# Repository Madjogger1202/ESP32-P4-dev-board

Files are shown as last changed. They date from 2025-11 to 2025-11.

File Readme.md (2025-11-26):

# ESP32-P4-dev-board

> High-performance vision and control board based on **ESP32-P4 (32 MB internal RAM)**.  
> Designed as a modern replacement for **OpenMV-style boards** built on STM32H7,  
> with integrated USB interfaces, Wi-Fi, camera connector, and expansion ports.

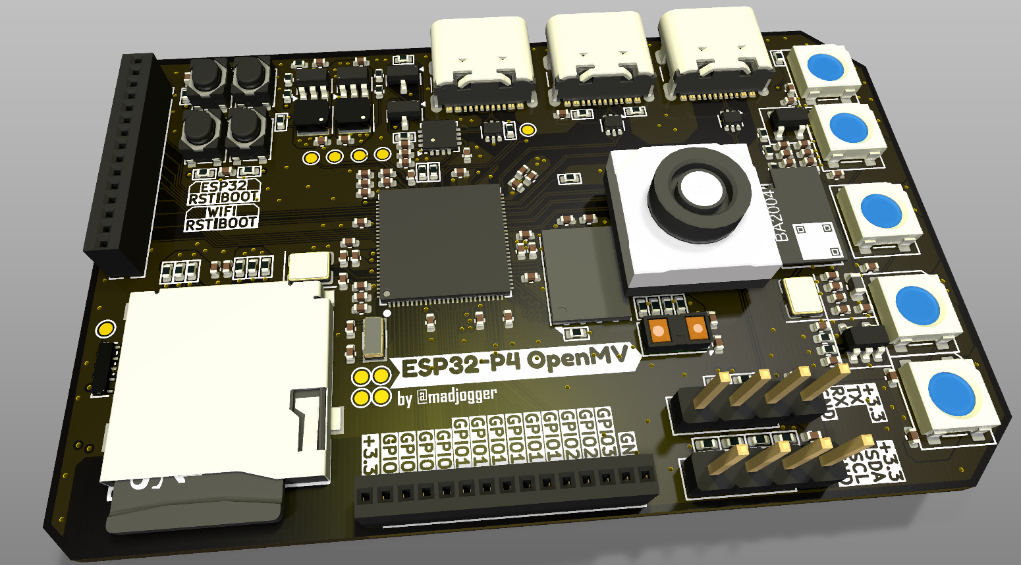
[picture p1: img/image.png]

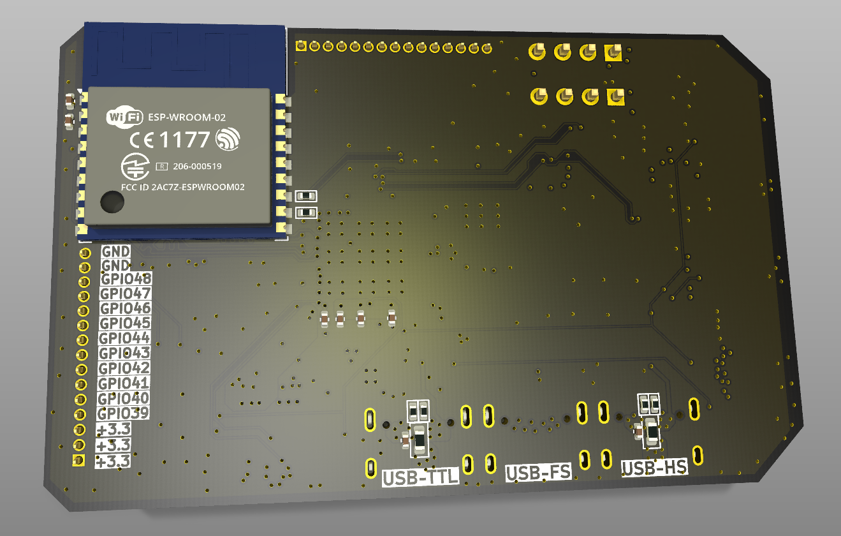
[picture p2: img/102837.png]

---

## Overview

ESP32-P4-dev-board combines imaging, communication, and compute capabilities in a single compact platform.  
The board supports **MIPI camera modules**, **microSD storage**, **Wi-Fi via ESP-WROOM-02**, and multiple USB interfaces for flexible development and deployment.

---

## Key Features

- **Main MCU:** ESP32-P4 (dual-core, 32 MB integrated PSRAM)
- **External Flash:** GD25Q256EYIGR (32 MByte QSPI)
- **Wi-Fi module:** ESP-WROOM-02 (UART connection to P4)
- **Distance sensor:** VL53L0CXV0DH1 (time-of-flight)
- **Camera interface:** DF30FC-24DS-0.4V_81 (2-lane MIPI, Raspberry Pi-compatible)
- **microSD slot:** 4-bit SDIO
- **5× WS2812B RGB LEDs** — for illumination or status visualization
- **Three USB ports:**
  - **USB-UART** (CH343P, auto-programming transistors)
  - **USB FS** — GPIO 24 / 25
  - **USB HS** — native high-speed
- **Expansion:**
  - Unused GPIOs routed to headers
  - Dedicated UART and I²C headers for peripheral modules
- **Design:** fully compliant with **ГОСТ** electrical documentation standards

---

## MCU Comparison — ESP32-P4 vs STM32H743 (OpenMV reference)

| Feature | **ESP32-P4** | **STM32H743 (OpenMV)** |
|:--|:--|:--|
| Architecture | Dual-core Xtensa LX7 | Single-core ARM Cortex-M7 |
| Clock frequency | up to **400 MHz** | up to **480 MHz** |
| Internal RAM | **32 MB unified PSRAM** | **1 MB SRAM** |
| External memory | QSPI Flash (32 MB) | QSPI Flash (32 MB external PSRAM optional) |
| Floating-point | Yes, single precision | Yes, single/double precision |
| SIMD / Vector | Yes (DSP extensions) | Yes |
| MIPI Camera | **2-lane CSI** | Parallel DCMI only |
| USB | **Dual USB (FS + HS)** | USB FS only |
| Wi-Fi / BT | External (ESP-WROOM-02) | None |
| Power domains | Integrated PMU | External regulators |
| Peripherals | I²S, SPI, I²C, SDIO, PWM, UART | I²S, SPI, I²C, SDIO, UART |
| Typical RAM bandwidth | ~3.2 GB/s internal | ~200 MB/s SRAM |
| Cost efficiency | Higher performance per $ | Mature ecosystem |
| OpenMV compatibility | Target-compatible (similar form-factor) | Native reference platform |

> ✅ **ESP32-P4** outperforms STM32H7 in memory bandwidth and integration,  
> enabling higher-resolution image processing and neural inference directly on-board.

---

## Power & Interfaces

| Function | Interface | Notes |
|:--|:--|:--|
| Power | USB-C / USB-UART | 5 V input |
| Programming | via CH343P (auto-boot/reset) | |
| Storage | microSD (SDIO 4-bit) | High-speed mode supported |
| Wi-Fi | ESP-WROOM-02 | UART link |
| Camera | MIPI-CSI 2-lane | Supports low-cost Pi-compatible modules |
| Distance sensor | VL53L0CXV0DH1 | I²C |
| LEDs | WS2812B × 5 | GPIO-controlled |
| Expansion | UART, I²C, GPIO headers | For custom peripherals |

---
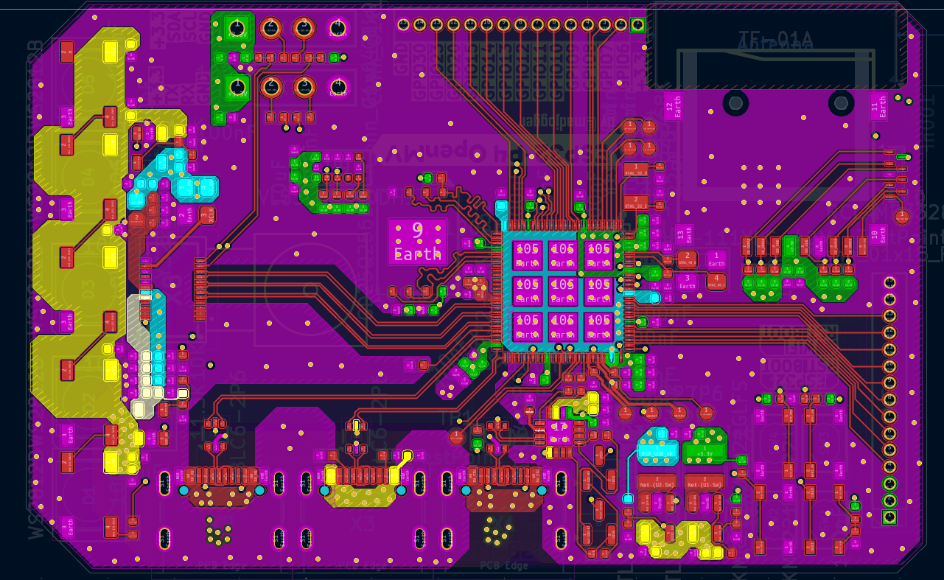
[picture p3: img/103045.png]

## Typical Applications

- Embedded **computer-vision** systems  
- **Robot control** and sensor fusion nodes  
- **Edge AI** and object-tracking experiments  
- Low-cost camera systems for prototyping and teaching  
- Drop-in **OpenMV replacement** with better memory and bandwidth

---

## Quick Use

1. Connect via **USB-UART** port for programming (auto-boot handled by CH343P).  
2. Flash firmware (ESP-IDF, MicroPython, or custom).  
3. Connect MIPI camera module to DF30FC-24DS connector.  
4. Optionally mount **microSD** for data logging.  
5. Power from any USB port (5 V).  
6. Use WS2812B LEDs for illumination or debug status.

---

## Notes

- Default PD profile: **5 V** (no PD negotiation required).  
- **ESP-WROOM-02** communicates only over UART (no SPI bridge).  
- **MIPI interface** is 2-lane, matching most low-cost Raspberry Pi-compatible cameras.  
- **Schematics and layout** follow ГОСТ formatting.  
- **All unconnected GPIOs** are routed to headers for expansion.

---

## Images
*(to be added)*  
- Board top view  
- Board bottom view  
- Top layer routing  

---

## ⚠️ Status

> ⚠️ This hardware is **unverified** — first prototype **not yet tested**.  
> Electrical connections and functionality may require validation and tuning.

---

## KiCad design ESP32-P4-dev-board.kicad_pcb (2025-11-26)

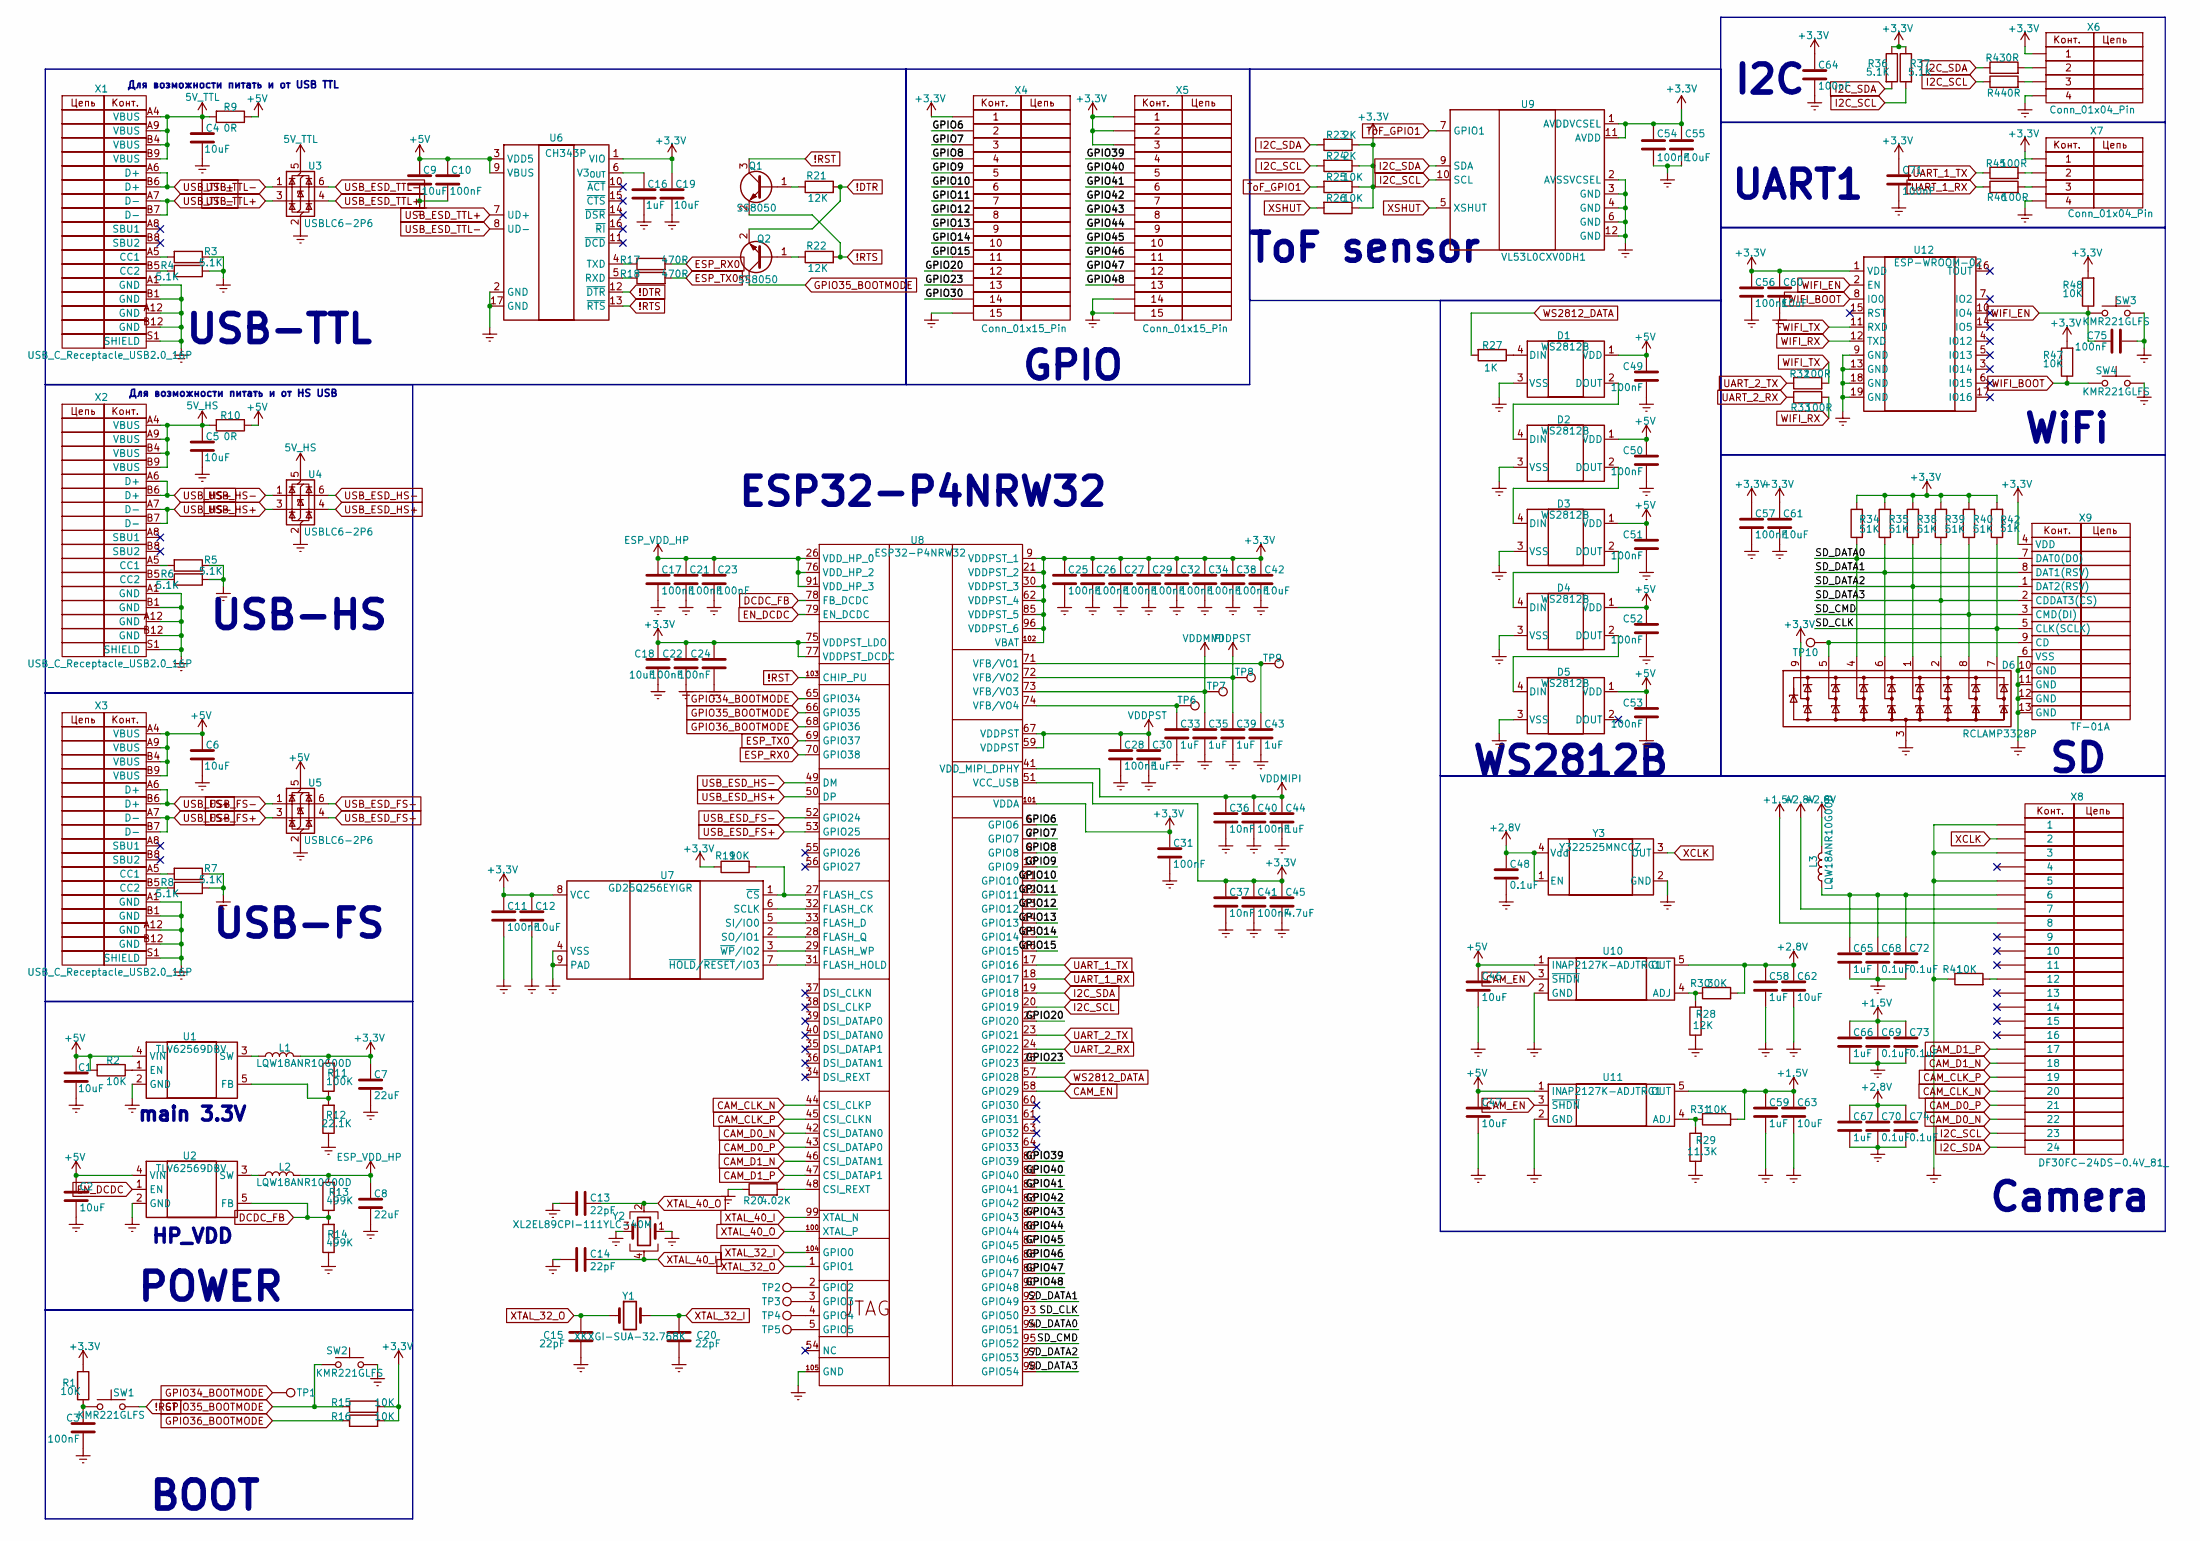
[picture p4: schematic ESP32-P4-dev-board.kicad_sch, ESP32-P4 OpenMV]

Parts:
C1, C2, C4, C5, C6, C9, C12, C18, C19, C42, C46, C47, C55, C60, C61, C62, C63: 10uF; C_0402_1005Metric
C3, C10, C11, C17, C21, C22, C23, C24, C25, C26, C27, C28, C29, C31, C32, C34, C38, C40, C41, C49, C50, C51, C52, C53, C54, C56, C57, C64, C71, C75: 100nF; C_0402_1005Metric
C7, C8: 22uF; C_0402_1005Metric
C13, C14, C15, C20: 22pF; C_0402_1005Metric
C16, C30, C33, C35, C39, C43, C44, C58, C59, C65, C66, C67: 1uF; C_0402_1005Metric
C36, C37: 10nF; C_0402_1005Metric
C45: 4.7uF; C_0402_1005Metric
C48, C68, C69, C70, C72, C73, C74: 0.1uF; C_0402_1005Metric
D1, D2, D3, D4, D5: WS2812B; LED_WS2812B_PLCC4_5.0x5.0mm_P3.2mm
D6: RCLAMP3328P; UDFN-9_1.0x3.8mm_P0.5mm
L1, L2: LQW18ANR10G00D; L_Wurth_WE-LQSH-3012
L3: LQW18ANR10G00D; L_0603_1608Metric
Q1, Q2: SS8050; SOT-23
R1, R2, R15, R16, R19, R25, R26, R31, R41, R47, R48: 10K; R_0402_1005Metric
R3, R4, R5, R6, R7, R8, R36, R37: 5.1K; R_0402_1005Metric
R9, R10: 0R; R_0603_1608Metric
R11: 100K; R_0402_1005Metric
R12: 22.1K; R_0402_1005Metric
R13, R14: 499K; R_0402_1005Metric
R17, R18: 470R; R_0402_1005Metric
R20: 4.02K; R_0402_1005Metric
R21, R22, R28: 12K; R_0402_1005Metric
R23, R24: 2K; R_0402_1005Metric
R27: 1K; R_0402_1005Metric
R29: 11.3K; R_0402_1005Metric
R30: 30K; R_0402_1005Metric
R32, R33, R45, R46: 100R; R_0402_1005Metric
R34, R35, R38, R39, R40, R42: 51K; R_0402_1005Metric
R43, R44: 0R; R_0402_1005Metric
SW1, SW2, SW3, SW4: KMR221GLFS; SW_SPST_PTS810
TP1, TP2, TP3, TP4, TP5, TP6, TP7, TP8, TP9, TP10: TestPoint; TestPoint_Pad_D1.0mm
U1, U2: TLV62569DBV; SOT-23-5
U3, U4, U5: USBLC6-2P6; SOT-666
U6: CH343P; WCH_QFN-16-1EP_3x3mm_P0.5mm_EP1.8x1.8mm
U7: GD25Q256EYIGR; WSON-8-1EP_8x6mm_P1.27mm_EP3.4x4.3mm
U8: ESP32-P4NRW32; Manufacturer Part ESP32-P4NRW32; LCSC Part Name ESP32-P4NRW32
U9: VL53L0CXV0DH1; ST_VL53L1x
U10, U11: AP2127K-ADJTRG1; SOT-23-5
U12: ESP-WROOM-02
X1, X2, X3: USB_C_Receptacle_USB2.0_16P; USB_C_Receptacle_GCT_USB4105-xx-A_16P_TopMnt_Horizontal
X4, X5: Conn_01x15_Pin; PinSocket_1x15_P1.27mm_Vertical
X6, X7: Conn_01x04_Pin; PinHeader_1x04_P2.54mm_Vertical
X8: DF30FC-24DS-0.4V_81_; DF30FC-24DS-0.4V(81); Manufacturer_Part_Number DF30FC-24DS-0.4V(81); Mouser Part Number 798-DF30FC24DS04V81
X9: TF-01A; Manufacturer Part TF-01A; LCSC Part Name 自弹式 MicroSD卡(TF卡) 卡座
Y1: XKXGI-SUA-32.768K; Crystal_SMD_3215-2Pin_3.2x1.5mm
Y2: XL2EL89CPI-111YLC-40M; Crystal_SMD_3225-4Pin_3.2x2.5mm
Y3: Y322525MNCCZ; Oscillator_SMD_Abracon_ASE-4Pin_3.2x2.5mm

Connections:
5V_HS: C5.1, R10.2, U4.5 (VBUS), X2.A4 (VBUS), X2.A9 (VBUS), X2.B4 (VBUS), X2.B9 (VBUS)
5V_TTL: C4.1, R9.2, U3.5 (VBUS), X1.A4 (VBUS), X1.A9 (VBUS), X1.B4 (VBUS), X1.B9 (VBUS)
!DTR: Q2.2 (E), R21.2, U6.12 (~DTR)
!RST: Q1.3 (C), SW1.2, U8.103 (CHIP_PU)
!RTS: Q1.2 (E), R22.2, U6.13 (~RTS)
+1.5V: C59.1, C63.1, C66.1, C69.1, C73.1, R31.2, U11.5 (OUT), X8.8
+2.8V: C48.1, C58.1, C62.1, C67.1, C70.1, C74.1, L3.1, R30.2, U10.5 (OUT), X8.7, Y3.1 (EN), Y3.4 (Vdd)
+3.3V: C7.1, C11.1, C12.1, C18.1, C19.1, C22.1, C24.1, C25.1, C26.1, C27.1, C29.1, C31.1, C32.1, C34.1, C37.1, C38.1, C41.1, C42.1, C45.1, C54.1, C55.1, C56.1, C57.1, C60.1, C61.1, C64.1, C71.1, D6.9 (K8), L1.1, R1.2, R11.2, R15.2, R16.2, R19.1, R23.1, R24.1, R25.1, R26.1, R34.2, R35.2, R36.1, R37.1, R38.2, R39.2, R40.2, R42.2, R47.2, R48.2, U6.1 (VIO), U7.8 (VCC), U8.9 (VDDPST_1), U8.21 (VDDPST_2), U8.30 (VDDPST_3), U8.51 (VCC_USB), U8.62 (VDDPST_4), U8.75 (VDDPST_LDO), U8.77 (VDDPST_DCDC), U8.85 (VDDPST_5), U8.96 (VDDPST_6), U8.101 (VDDA), U8.102 (VBAT), U9.1 (AVDDVCSEL), U9.11 (AVDD), U12.1 (VDD), X4.1, X5.1, X5.2, X5.3, X6.1, X7.1, X9.4 (VDD)
+5V: C1.1, C2.1, C6.1, C9.1, C10.1, C46.1, C47.1, C49.1, C50.1, C51.1, C52.1, C53.1, D1.1 (VDD), D2.1 (VDD), D3.1 (VDD), D4.1 (VDD), D5.1 (VDD), R2.2, R9.1, R10.1, U1.4 (VIN), U2.4 (VIN), U5.5 (VBUS), U6.3 (VDD5), U6.9 (VBUS), U10.1 (IN), U11.1 (IN), X3.A4 (VBUS), X3.A9 (VBUS), X3.B4 (VBUS), X3.B9 (VBUS)
/GPIO6: U8.6 (GPIO6), X4.2
/GPIO7: U8.7 (GPIO7), X4.3
/GPIO8: U8.8 (GPIO8), X4.4
/GPIO9: U8.10 (GPIO9), X4.5
/GPIO10: U8.11 (GPIO10), X4.6
/GPIO11: U8.12 (GPIO11), X4.7
/GPIO12: U8.13 (GPIO12), X4.8
/GPIO13: U8.14 (GPIO13), X4.9
/GPIO14: U8.15 (GPIO14), X4.10
/GPIO15: U8.16 (GPIO15), X4.11
/GPIO20: U8.22 (GPIO20), X4.12
/GPIO23: U8.25 (GPIO23), X4.13
/GPIO30: X4.14
/GPIO39: U8.80 (GPIO39), X5.4
/GPIO40: U8.81 (GPIO40), X5.5
/GPIO41: U8.82 (GPIO41), X5.6
/GPIO42: U8.83 (GPIO42), X5.7
/GPIO43: U8.84 (GPIO43), X5.8
/GPIO44: U8.86 (GPIO44), X5.9
/GPIO45: U8.87 (GPIO45), X5.10
/GPIO46: U8.88 (GPIO46), X5.11
/GPIO47: U8.89 (GPIO47), X5.12
/GPIO48: U8.90 (GPIO48), X5.13
/SD_CLK: D6.7 (K6), R42.1, U8.93 (GPIO50), X9.5 (CLK(SCLK))
/SD_CMD: D6.8 (K7), R40.1, U8.95 (GPIO52), X9.3 (CMD(DI))
/SD_DATA0: D6.4 (K3), R34.1, U8.94 (GPIO51), X9.7 (DAT0(D0))
/SD_DATA1: D6.6 (K5), R35.1, U8.92 (GPIO49), X9.8 (DAT1(RSV))
/SD_DATA2: D6.1 (K1), R38.1, U8.97 (GPIO53), X9.1 (DAT2(RSV))
/SD_DATA3: D6.2 (K2), R39.1, U8.98 (GPIO54), X9.2 (CDDAT3(CS))
CAM_CLK_N: U8.44 (CSI_CLKP), X8.20
CAM_CLK_P: U8.45 (CSI_CLKN), X8.19
CAM_D0_N: U8.42 (CSI_DATAN0), X8.22
CAM_D0_P: U8.43 (CSI_DATAP0), X8.21
CAM_D1_N: U8.46 (CSI_DATAN1), X8.18
CAM_D1_P: U8.47 (CSI_DATAP1), X8.17
CAM_EN: U8.58 (GPIO29), U10.3 (~SHDN), U11.3 (~SHDN)
DCDC_FB: R13.1, R14.2, U2.5 (FB), U8.78 (FB_DCDC)
EN_DCDC: U2.1 (EN), U8.79 (EN_DCDC)
ESP_RX0: R17.2, U8.70 (GPIO38)
ESP_TX0: R18.2, U8.69 (GPIO37)
ESP_VDD_HP: C8.1, C17.1, C21.1, C23.1, L2.1, R13.2, U8.26 (VDD_HP_0), U8.76 (VDD_HP_2), U8.91 (VDD_HP_3)
Earth: C1.2, C2.2, C3.2, C4.2, C5.2, C6.2, C7.2, C8.2, C9.2, C10.2, C11.2, C12.2, C13.2, C14.2, C15.1, C16.2, C17.2, C18.2, C19.2, C20.1, C21.2, C22.2, C23.2, C24.2, C25.2, C26.2, C27.2, C28.2, C29.2, C30.2, C31.2, C32.2, C33.2, C34.2, C35.2, C36.2, C37.2, C38.2, C39.2, C40.2, C41.2, C42.2, C43.2, C44.2, C45.2, C46.2, C47.2, C48.2, C49.2, C50.2, C51.2, C52.2, C53.2, C54.2, C55.2, C56.2, C57.2, C58.2, C59.2, C60.2, C61.2, C62.2, C63.2, C64.2, C65.2, C66.2, C67.2, C68.2, C69.2, C70.2, C71.2, C72.2, C73.2, C74.2, C75.2, D1.3 (VSS), D2.3 (VSS), D3.3 (VSS), D4.3 (VSS), D5.3 (VSS), D6.3 (A), R3.1, R4.2, R5.1, R6.2, R7.1, R8.2, R12.1, R14.1, R20.1, R28.1, R29.1, R41.1, SW2.1, SW3.1, SW4.2, U1.2 (GND), U2.2 (GND), U3.2 (GND), U4.2 (GND), U5.2 (GND), U6.2 (GND), U6.17 (GND), U7.4 (VSS), U7.9 (PAD), U8.105 (GND), U9.2 (AVSSVCSEL), U9.3 (GND), U9.4 (GND), U9.6 (GND), U9.12 (GND), U10.2 (GND), U11.2 (GND), U12.9 (GND), U12.13 (GND), U12.18 (GND), U12.19 (GND), X1.A1 (GND), X1.A12 (GND), X1.B1 (GND), X1.B12 (GND), X1.S1 (SHIELD), X2.A1 (GND), X2.A12 (GND), X2.B1 (GND), X2.B12 (GND), X2.S1 (SHIELD), X3.A1 (GND), X3.A12 (GND), X3.B1 (GND), X3.B12 (GND), X3.S1 (SHIELD), X4.15, X5.14, X5.15, X6.4, X7.4, X8.1, X8.3, X8.5, X9.6 (VSS), X9.10 (GND), X9.11 (GND), X9.12 (GND), X9.13 (GND), Y2.1, Y2.3, Y3.2 (GND)
GPIO34_BOOTMODE: TP1.1, U8.65 (GPIO34)
GPIO35_BOOTMODE: Q2.3 (C), R15.1, SW2.2, U8.66 (GPIO35)
GPIO36_BOOTMODE: R16.1, U8.68 (GPIO36)
I2C_SCL: R24.2, R37.2, R44.1, U8.20 (GPIO19), U9.10 (SCL), X8.23
I2C_SDA: R23.2, R36.2, R43.1, U8.19 (GPIO18), U9.9 (SDA), X8.24
unnamed: C3.1, R1.1, SW1.1
unnamed: C65.1, C68.1, C72.1, L3.2, X8.6
unnamed: D1.4 (DIN), R27.1
unnamed: D1.2 (DOUT), D2.4 (DIN)
unnamed: D2.2 (DOUT), D3.4 (DIN)
unnamed: D3.2 (DOUT), D4.4 (DIN)
unnamed: D4.2 (DOUT), D5.4 (DIN)
unnamed: D6.5 (K4), TP10.1, X9.9 (CD)
unnamed: Q1.1 (B), R21.1
unnamed: Q2.1 (B), R22.1
unnamed: R41.2, X8.12
unnamed: R2.1, U1.1 (EN)
unnamed: R11.1, R12.2, U1.5 (FB)
unnamed: L1.2, U1.3 (SW)
unnamed: L2.2, U2.3 (SW)
unnamed: R18.1, U6.5 (RXD)
unnamed: R17.1, U6.4 (TXD)
unnamed: C16.1, U6.6 (V3_{OUT})
unnamed: U7.6 (SCLK), U8.32 (FLASH_CK)
unnamed: U7.5 (SI/IO0), U8.33 (FLASH_D)
unnamed: U7.2 (SO/IO1), U8.28 (FLASH_Q)
unnamed: R19.2, U7.1 (~CS), U8.27 (FLASH_CS)
unnamed: U7.7 (~HOLD/~RESET/IO3), U8.31 (FLASH_HOLD)
unnamed: U7.3 (~WP/IO2), U8.29 (FLASH_WP)
unnamed: R20.2, U8.48 (CSI_REXT)
unnamed: TP2.1, U8.2 (GPIO2)
unnamed: TP3.1, U8.3 (GPIO3)
unnamed: TP4.1, U8.4 (GPIO4)
unnamed: TP5.1, U8.5 (GPIO5)
unnamed: C43.1, TP9.1, U8.71 (VFB/VO1)
unnamed: C33.1, TP6.1, U8.74 (VFB/VO4)
unnamed: R28.2, R30.1, U10.4 (ADJ)
unnamed: R29.2, R31.1, U11.4 (ADJ)
unnamed: R3.2, X1.A5 (CC1)
unnamed: R4.1, X1.B5 (CC2)
unnamed: R5.2, X2.A5 (CC1)
unnamed: R6.1, X2.B5 (CC2)
unnamed: R7.2, X3.A5 (CC1)
unnamed: R8.1, X3.B5 (CC2)
unnamed: R43.2, X6.2
unnamed: R44.2, X6.3
unnamed: R45.2, X7.2
unnamed: R46.2, X7.3
ToF_GPIO1: R25.2, U9.7 (GPIO1)
UART_1_RX: R46.1, U8.18 (GPIO17)
UART_1_TX: R45.1, U8.17 (GPIO16)
UART_2_RX: R33.1, U8.24 (GPIO22)
UART_2_TX: R32.1, U8.23 (GPIO21)
USB_ESD_FS+: U5.4 (I/O2), U8.53 (GPIO25)
USB_ESD_FS-: U5.6 (I/O1), U8.52 (GPIO24)
USB_ESD_HS+: U4.4 (I/O2), U8.50 (DP)
USB_ESD_HS-: U4.6 (I/O1), U8.49 (DM)
USB_ESD_TTL+: U3.4 (I/O2), U6.7 (UD+)
USB_ESD_TTL-: U3.6 (I/O1), U6.8 (UD-)
USB_FS+: U5.3 (I/O2), X3.A6 (D+), X3.B6 (D+)
USB_FS-: U5.1 (I/O1), X3.A7 (D-), X3.B7 (D-)
USB_HS+: U4.3 (I/O2), X2.A6 (D+), X2.B6 (D+)
USB_HS-: U4.1 (I/O1), X2.A7 (D-), X2.B7 (D-)
USB_TTL+: U3.3 (I/O2), X1.A6 (D+), X1.B6 (D+)
USB_TTL-: U3.1 (I/O1), X1.A7 (D-), X1.B7 (D-)
VDDMIPI: C35.1, C36.1, C40.1, C44.1, TP7.1, U8.41 (VDD_MIPI_DPHY), U8.73 (VFB/VO3)
VDDPST: C28.1, C30.1, C39.1, TP8.1, U8.59 (VDDPST), U8.67 (VDDPST), U8.72 (VFB/VO2)
WIFI_BOOT: R47.1, SW4.1, U12.8 (IO0)
WIFI_EN: C75.1, R48.1, SW3.2, U12.2 (EN)
WIFI_RX: R33.2, U12.12 (TXD)
WIFI_TX: R32.2, U12.11 (RXD)
WS2812_DATA: R27.2, U8.57 (GPIO28)
XCLK: X8.2, Y3.3 (OUT)
XSHUT: R26.2, U9.5 (XSHUT)
XTAL_32_I: C20.2, U8.104 (GPIO0), Y1.2
XTAL_32_O: C15.2, U8.1 (GPIO1), Y1.1
XTAL_40_I: C14.1, U8.99 (XTAL_N), Y2.4
XTAL_40_O: C13.1, U8.100 (XTAL_P), Y2.2

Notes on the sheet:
Для возможности питать и от USB TTL
POWER
UART1
main 3.3V
HP_VDD
BOOT
Camera
WS2812B
USB-TTL
ToF sensor
I2C
Для возможности питать и от HS USB
WiFi
USB-HS
GPIO
ESP32-P4NRW32
USB-FS

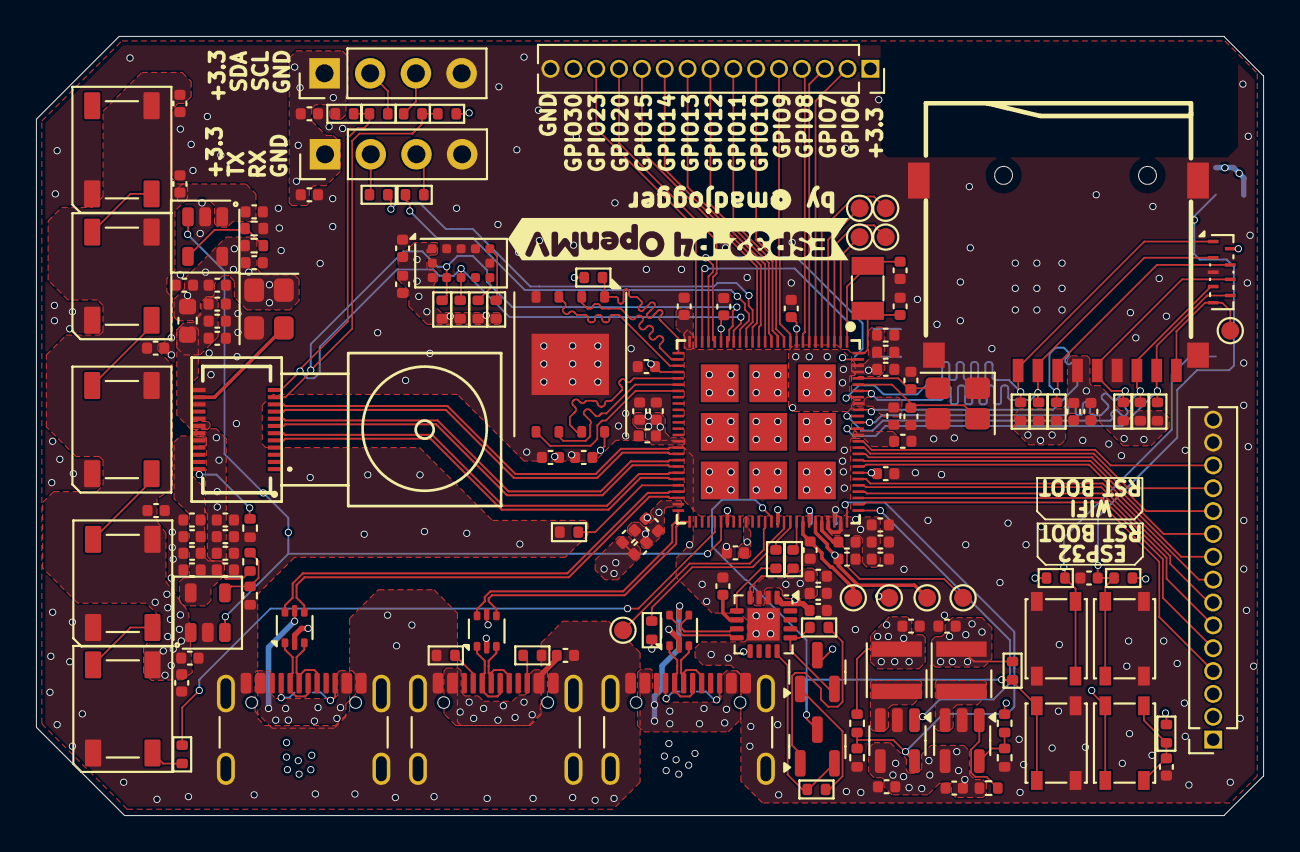
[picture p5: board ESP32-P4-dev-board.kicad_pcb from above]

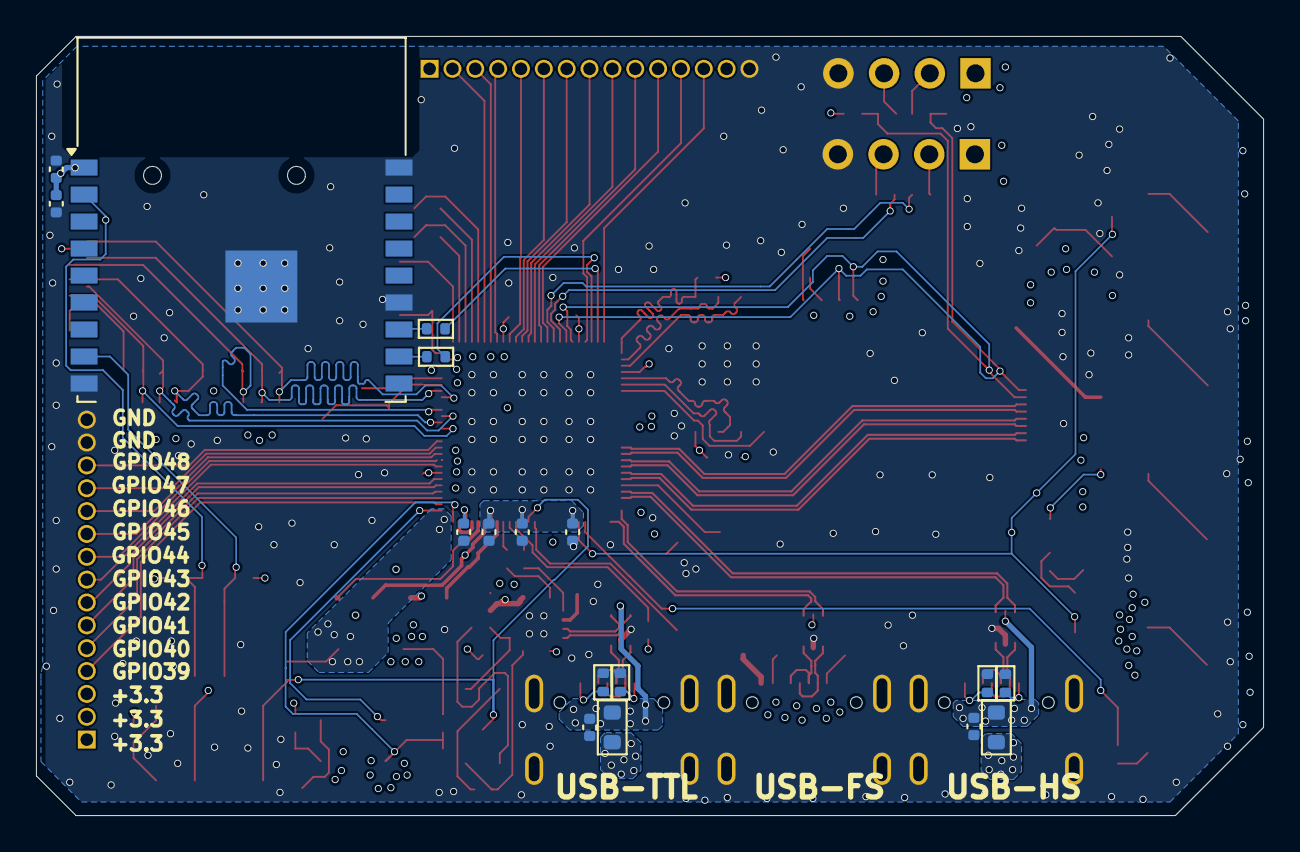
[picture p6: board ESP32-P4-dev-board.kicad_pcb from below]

Board: 4 copper layers, 68.2 x 43.3 mm, 173 parts (17 on the bottom side), 128 nets.

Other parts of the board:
kibuzzard-6926A799: G***; kibuzzard-6926A799

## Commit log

2025-11-24 schematics ready
    [ESP32-P4-dev-board.kicad_pcb, ESP32-P4-dev-board.kicad_sch]
2025-11-25 трассировка и проверка завершены
    [ESP32-P4-dev-board.kicad_pcb, ESP32-P4-dev-board.kicad_sch]
2025-11-26 Rev 0 ready
    [ESP32-P4-dev-board.kicad_pcb]
